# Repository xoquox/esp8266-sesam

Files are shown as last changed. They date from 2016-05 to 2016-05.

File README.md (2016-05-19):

# esp8266-sesam

Universal Wifi door opener. 

A project by [schinken](https://github.com/schinken "schinkens Github") and [xoquox](https://github.com/xoquox "xoquoxs Github")

# Hardware

Our hardware works with a ESP-08 or ESP-12e modul. It uses nice little DIL relays, becaus we can direct control them with TTL-signals. What I think is very nice for a relay. 

# Webinterface
  TODO

# REST-API
  TODO

# License
  TODOh

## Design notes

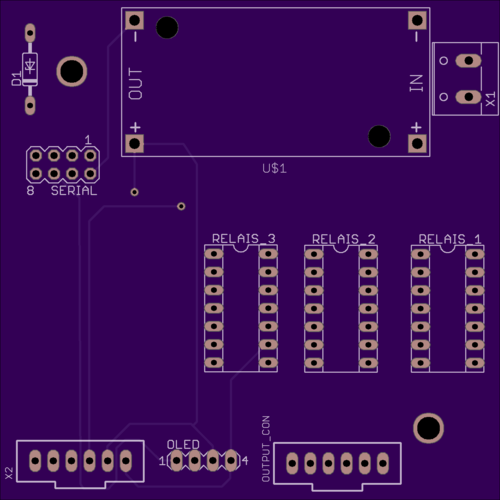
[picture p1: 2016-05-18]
hardware/images/board_bottom.png

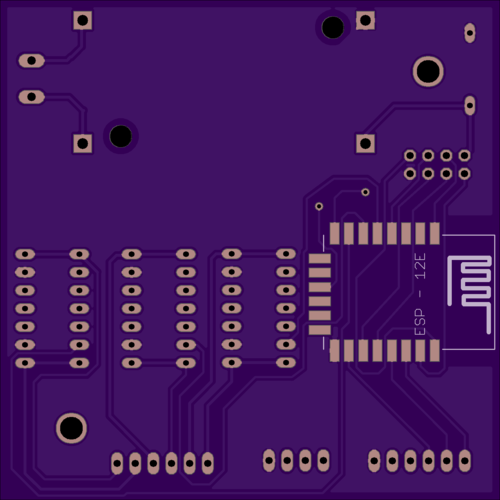
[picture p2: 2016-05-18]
hardware/images/board_top.png

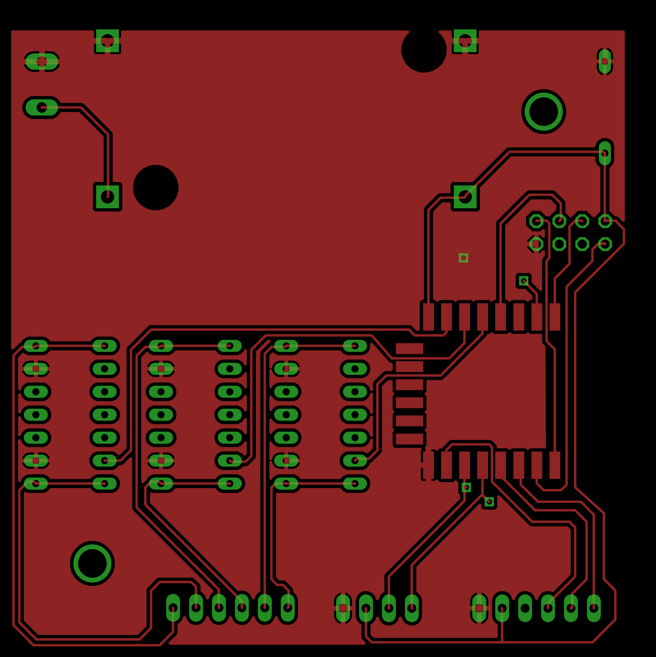
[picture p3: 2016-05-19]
hardware/!eagle_export.png

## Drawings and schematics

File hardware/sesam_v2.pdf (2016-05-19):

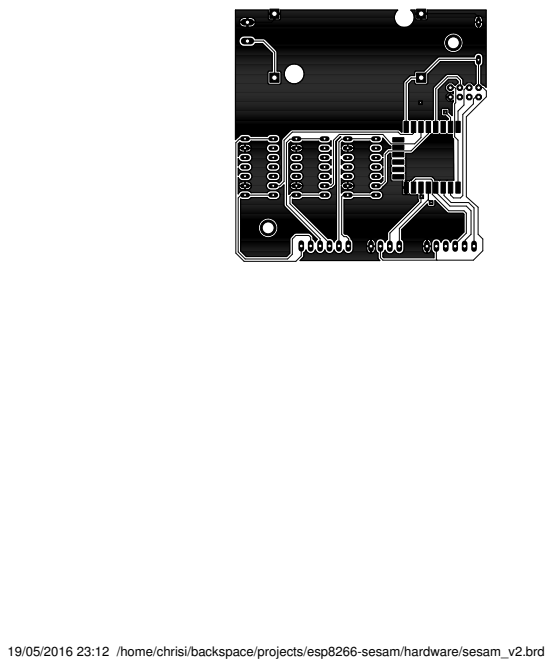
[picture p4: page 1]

19/05/2016 23:12 /home/chrisi/backspace/projects/esp8266-sesam/hardware/sesam_v2.brd

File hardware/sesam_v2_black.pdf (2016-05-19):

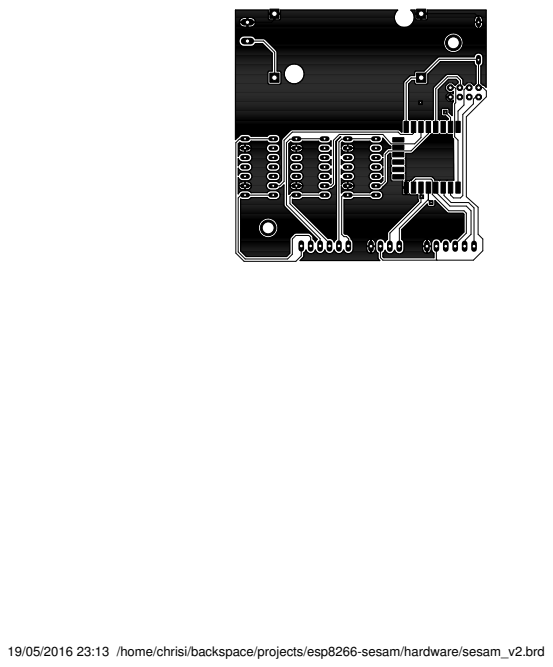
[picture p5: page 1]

19/05/2016 23:13 /home/chrisi/backspace/projects/esp8266-sesam/hardware/sesam_v2.brd

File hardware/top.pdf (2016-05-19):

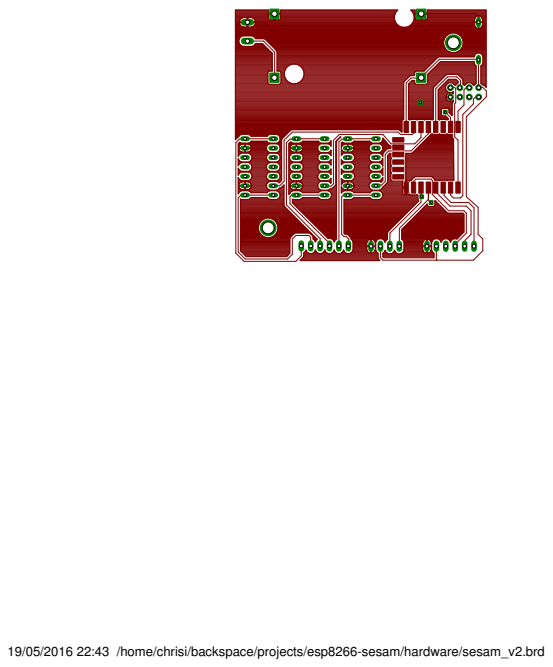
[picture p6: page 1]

19/05/2016 22:43 /home/chrisi/backspace/projects/esp8266-sesam/hardware/sesam_v2.brd

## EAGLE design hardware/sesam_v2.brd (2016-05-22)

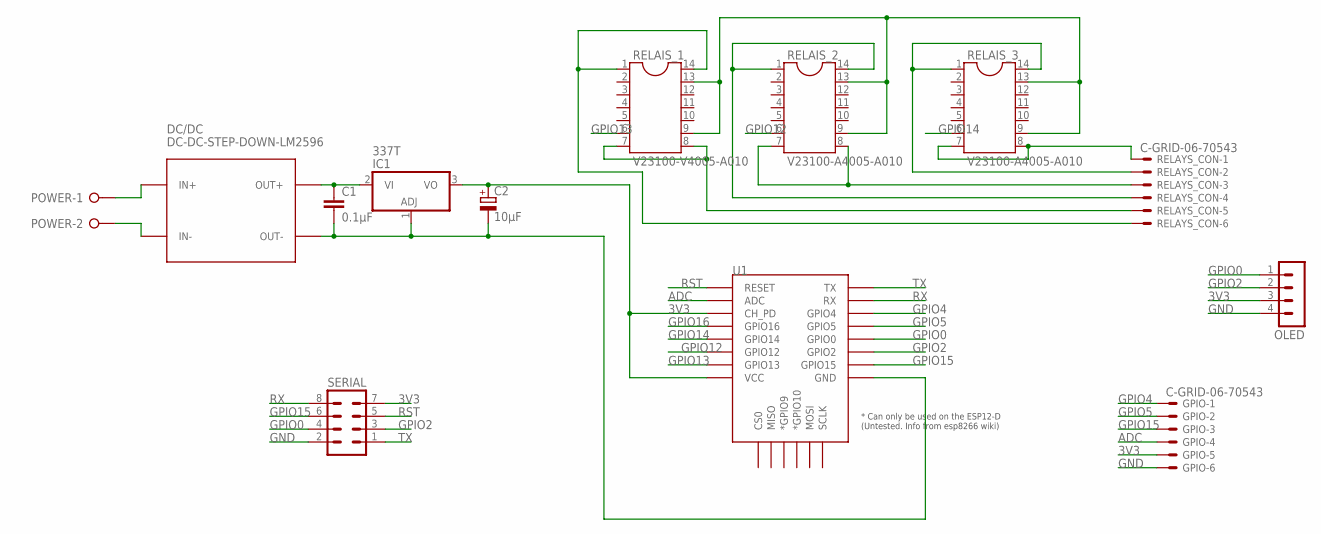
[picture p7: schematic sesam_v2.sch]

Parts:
C1: 0.1µF; C0805
C2: 10µF; E2-5
DC/DC: DC-DC-STEP-DOWN-LM2596
GPIO: C-GRID-06-70543; 70543-06
IC1: 337T; TO220H
OLED: MA04-1
POWER: W237-02P; W237-132
RELAIS_1: V23100-V4005-A010; SOCKET-14
RELAIS_2, RELAIS_3: V23100-A4005-A010; SOCKET-14
RELAYS_CON: C-GRID-06-70543; 70543-06
SERIAL: MA04-2
U1: ESP12ESMD; ESP12E-SMD

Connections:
3V3: C2.+, GPIO.5, IC1.3 (VO), OLED.3, SERIAL.7, U1.CH_PD, U1.VCC
ADC: GPIO.4, U1.ADC
GND: C1.2, C2.-, DC/DC.IN-, DC/DC.OUT-, GPIO.6, IC1.1 (ADJ), OLED.4, POWER.2, RELAIS_1.9, RELAIS_1.13, RELAIS_2.9, RELAIS_2.13, RELAIS_3.9, RELAIS_3.13, SERIAL.2, U1.GND
GPIO0: OLED.1, SERIAL.4, U1.GPIO0
GPIO2: OLED.2, SERIAL.3, U1.GPIO2
GPIO4: GPIO.1, U1.GPIO4
GPIO5: GPIO.2, U1.GPIO5
GPIO12: RELAIS_2.6, U1.GPIO12
GPIO13: RELAIS_1.6, U1.GPIO13
GPIO14: RELAIS_3.6, U1.GPIO14
GPIO15: GPIO.3, SERIAL.6, U1.GPIO15
GPIO16: U1.GPIO16
unnamed: RELAIS_3.1, RELAIS_3.14, RELAYS_CON.2
unnamed: DC/DC.IN+, POWER.1
unnamed: RELAIS_3.7, RELAIS_3.8, RELAYS_CON.1
unnamed: RELAIS_2.1, RELAIS_2.14, RELAYS_CON.4
unnamed: RELAIS_2.7, RELAIS_2.8, RELAYS_CON.3
unnamed: RELAIS_1.1, RELAIS_1.14, RELAYS_CON.6
unnamed: RELAIS_1.7, RELAIS_1.8, RELAYS_CON.5
POWER: C1.1, DC/DC.OUT+, IC1.2 (VI)
RST: SERIAL.5, U1.RESET
RX: SERIAL.8, U1.RXD0 (RX)
TX: SERIAL.1, U1.TXD0 (TX)

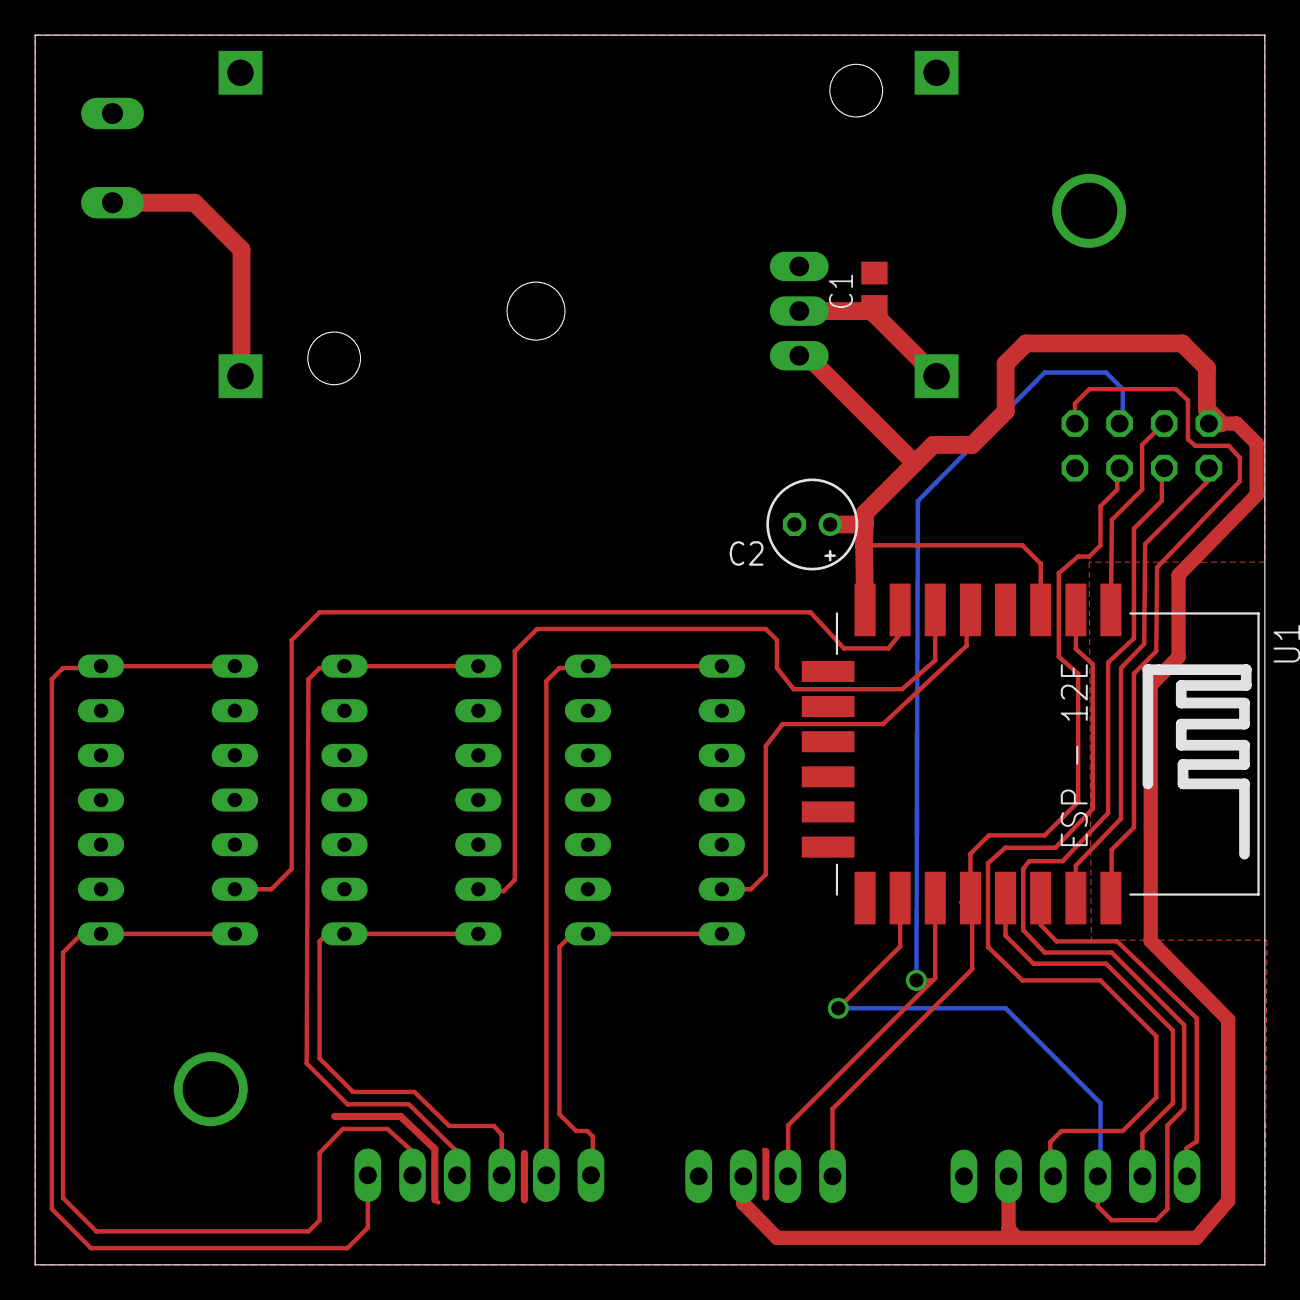
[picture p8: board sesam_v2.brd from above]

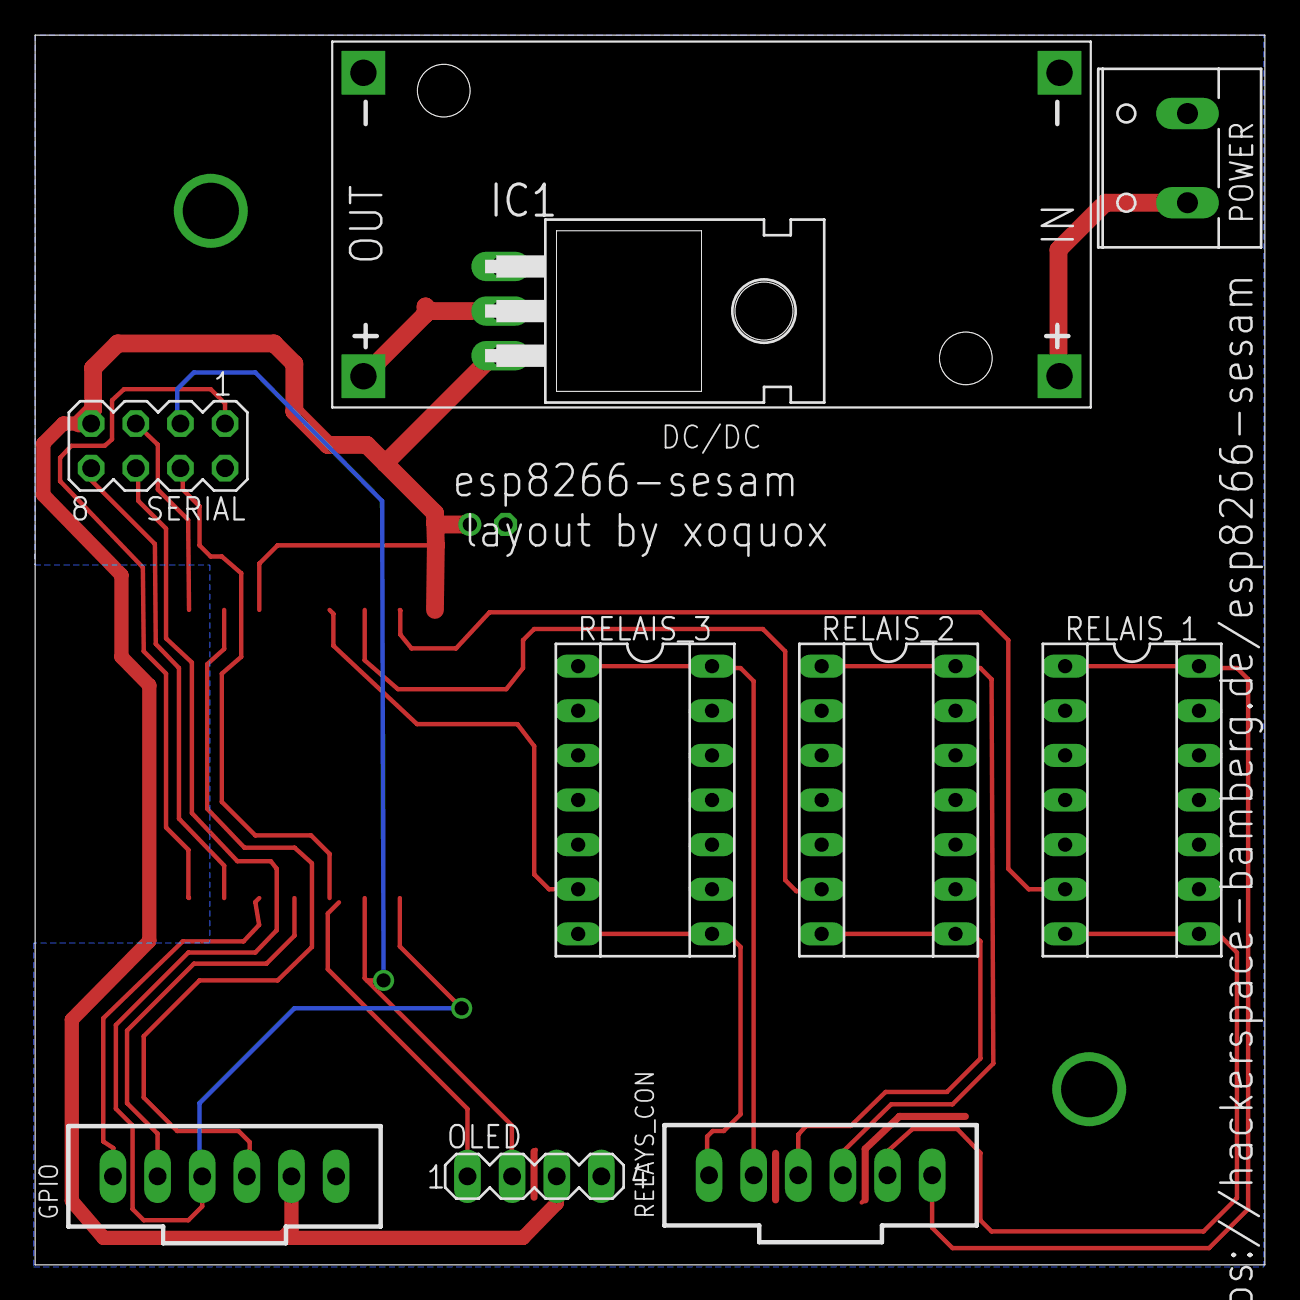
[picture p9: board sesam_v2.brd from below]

Board: 2 copper layers, 70.0 x 70.0 mm, 13 parts (10 on the bottom side), 22 nets.

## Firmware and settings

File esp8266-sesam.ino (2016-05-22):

#include <ESP8266WiFi.h>
#include <WiFiClient.h> 
#include <ArduinoJson.h>
#include <ESP8266WebServer.h>
#include <SimpleTimer.h>
#include "static.h"
#include "settings.h"

const PROGMEM char text_html[] = "text/html";
const PROGMEM char text_css[] = "text/css";

////////////////////////////////////////////////////////
// Awesome code....

ESP8266WebServer server(80);
SimpleTimer timer;

typedef struct {
  const char* name;
  const char* route;
  uint8_t pin;
  uint16_t holdMs;
} t_endpoint;

t_endpoint endpoints[] = {
  { "Garagentor", "/relais/garageDoor", D5, 1000 },
  { "Haustür", "/relais/frontDoor",  D6, 1000 }
};

void setup() {
  delay(1000);
  Serial.begin(115200);
  Serial.println();
  Serial.print("Configuring access point...");

  WiFi.mode(WIFI_AP);
  WiFi.softAP(ssid, password);

  IPAddress myIP = WiFi.softAPIP();
  Serial.print("AP IP address: ");
  Serial.println(myIP);

  
  server.on("/", []() {
    server.sendHeader("Pragma", "no-cache");
    server.sendHeader("Expires", "0");
    server.sendHeader("Cache-Control", "no-cache, no-store, must-revalidate");
    
    server.send_P(200, text_html, static_index_html);
  });


  server.on("/relais", []() {
    DynamicJsonBuffer jsonBuffer;
    
    JsonObject& root = jsonBuffer.createObject();
    JsonArray& jsonEndpoints = root.createNestedArray("relais");
    
    for(t_endpoint endpoint : endpoints) {
      JsonObject& entry = jsonBuffer.createObject();
      entry["name"] = endpoint.name;
      entry["url"] = endpoint.route;
    
      jsonEndpoints.add(entry);
    }

    String response = "";
    root.printTo(response);

    server.send(200, "application/json", response);
  });

  for(t_endpoint endpoint : endpoints) {

    pinMode(endpoint.pin, OUTPUT);
    
    server.on(endpoint.route, [endpoint]() {
      digitalWrite(endpoint.pin, HIGH);
      
      timer.setTimeout(endpoint.holdMs, [endpoint]() {
        digitalWrite(endpoint.pin, LOW);
      });   
  
      server.sendHeader("Pragma", "no-cache");
      server.sendHeader("Expires", "0");
      server.sendHeader("Cache-Control", "no-cache, no-store, must-revalidate");

      server.send(200, "text/plain", "OK");
    });
  }
    
  server.begin();
  Serial.println("HTTP server started");
}

void loop() {
  server.handleClient();
  timer.run();
}

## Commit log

2016-05-16 hardware files added
    [sesam_v2.brd, sesam_v2.sch]
2016-05-18 new layout by hallojoh
    [sesam_v2.brd]
2016-05-18 new layout, all non smd components mirrored
    [sesam_v2.sch]
2016-05-19 minor changes
    [sesam_v2.brd]
2016-05-19 little changes
    [sesam_v2.brd, sesam_v2.sch]
2016-05-19 new nice layout
    [sesam_v2.brd, sesam_v2.sch]
2016-05-19 ready for first board
    [sesam_v2.brd, sesam_v2.sch]
2016-05-20 minor tweeks
    [sesam_v2.brd]
2016-05-21 nice new layout and board, better power supply added
    [sesam_v2.brd, sesam_v2.sch]
2016-05-21 fixed power regulator
    [sesam_v2.brd, sesam_v2.sch]
2016-05-22 some layout tweeks
    [sesam_v2.brd, sesam_v2.sch]
2016-05-22 fixed GND connections
    [sesam_v2.brd]
2016-05-22 Make button/relais configurable
2016-05-22 Fix button width
2016-05-22 More margin between buttons

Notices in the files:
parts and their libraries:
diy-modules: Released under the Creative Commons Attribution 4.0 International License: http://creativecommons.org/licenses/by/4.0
